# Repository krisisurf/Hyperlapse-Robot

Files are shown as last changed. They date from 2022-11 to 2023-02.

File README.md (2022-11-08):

# Hyperlapse-Robot
An remote-controlled electric mobile robot for creating hyperlapse videos using RaspberryPi and Arduino. Facilitates the process of capturing a so-called "hyperlapse/time-lapse" videos by precisely moving the position of the robot between the individual shots to add a depth-of-field effect to the final video.

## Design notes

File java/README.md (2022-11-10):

# Java Spring Application for Raspberry Pi

The Graphical User Interface of the project, which manages services to control the Arduino by sending JSON string with rules/commands to it.
The connection is one-directional (`RaspberryPI -> Arduino`) and it is made via `I2C protocol`.

## Setup Instructions
1. Open `java/Hyperlapse-Robot` project with IntelliJ or other Java IDE.
2. Run Maven command:
          ```
          mvn clean install
          ```
3. After the build is ready, copy the exported jar file `./target/Hyperlapse-Robot-0.0.1-SNAPSHOT.jar` to the Raspberry Pi
4. Enable I2C on the Raspberry Pi. You can see how [here](https://ozzmaker.com/i2c/).
5. Wire `RaspberryPi Zero 2W` with the `Arduino MEGA 2560` using pinouts.<table>
          <tr>
            <th>Raspberry Pi</th>
            <th>Arduino</th>
          </tr>
          <tr>
            <td>Ground</td>
            <td>Ground</td>
          </tr>
          <tr>
            <td>GPIO 2 Serial Data (I2C)</td>
            <td>SDA (D20)</td>
          </tr>
          <tr>
            <td>GPIO 3 Serial Clock (I2C)</td>
            <td>SCL (D21)</td>
          </tr>
    </table><p><span class="small">Optional for Arduino MEGA 2560: Digital IO Pins 20 and 21 can be configured as SDA (20) and SCL (21) to support I2C or I2C or Two Wire Interface (TWI) communication.</span></p>
6. Power on the Arduino and Raspberry Pi.
7. Run the java application on the Raspberry Pi. Navigate to the location of the jar file and run the command:
          ```
          sudo java -jar Hyperlapse-Robot-0.0.1-SNAPSHOT.jar
          ```
8. You are ready to open the GUI interface in the browser.

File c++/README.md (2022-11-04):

Using Arduino MEGA 2560 board.
Modules:
  * (4x) Step Motor 28BYj-48
  * (4x) ULN2003 driver board
  * Power source

arduino_steppers

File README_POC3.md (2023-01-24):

# Робот за създаване на hyperlapse/timelapse видеоклипове

## Описание:
> Електрически мобилен робот с отдалечено управление за създаване на "hyperlapse" видеоклипове с помощта на RaspberryPi компютър. Улеснява процеса на заснемането на така наречената "hyperlapse/time-lapse" фотография, като между отделните снимки се извършва прецизно преместване на позицията на робота, за да се придаде дълбочинен ефект на крайния видеоклип.
<sub>[Виж какво е hyperlapse тук.](https://youtu.be/y_4p6_KsqoE)</sub>

<table>
      <tr>
        <th>Софтуерна архитектура</th>
      </tr>
      <tr>
        <td>
          Software Architecture
        </td>
      </tr>
      </table>

>#### Frontend:</br>
>   - Мобилно приложение, което позволява на потребителя да създава и изпраща инструкции за движение към робота по интернет връзка.
>#### Hyperlapse Robot:</br>
>   - Spring Boot back-end - Сървърна програма, приемаща инструкции и изпращата ги към Control Board
>   - Control Board - Arduino микрокомпютър, който приема инструкции и контролира въртенето на стъпковите мотори
>   - Step Motors - стъпкови мотори, чрез които се извършва движението на робота и насочването на поставката за камера

## Главни функционалности на робота
1. Движение (напред, назад, с завой) по зададео разстояние и време за изпълнение.
2. Насочване на поставката за камера по зададени градусни мярки и време за изпълнение.
3. Мобилно приложение за управление, предназначено да се свързва с робота по WI-FI връзка.
   - бързо и лесно създаване на инструкции за движение
   - възможност за създаване на множество инструкции, които да се изпратят и изпълнят от робота
   - удобни за потребителя менюта за въвеждане на числови данни (растояние, време, градусни мярки).
4. Автоматично включване на робота, когато той се захранва от батерия/power bank

## Диаграми и изображения:
1. Хардуерна диаграма на архитектурата
    <table>
      <tr>
        <th>Hardware Wire диаграма</th>
      </tr>
      <tr>
        <td>
          Hardware Wire Architecture
        </td>
      </tr>
    </table>

2. DEMO, изработка по време на POC 2:
    <table>
          <th>
            <td>
                photo of the robot
            </td>
            <td>
                components inside the robot
            </td>
          </th>
    </table>

3. Изглед на мобилното приложение
      <table>
          <tr>
            <td>
                main window
            </td>
            <td>
                connection window
            </td>
            <td>
                create rule window
            </td>
          </tr>
          <tr>
            <td>
                create rule window
            </td>
            <td>
                create rule window
            </td>
            <td>
                main window
            </td>
          </tr>
      </table>

4. Изработка на 3D-модел на робота (3D принтер):
   - Вариант 1
   Hyperlapse-Robot
   - Подобрена версия на вариант 1
   Hyperlapse-robot-render-v2-jpeg

## Използвани технологии
- IntelliJ IDEA Community Edition
  - Разработка, чрез [Java Spring Boot](https://spring.io/projects/spring-boot).
  - библиотека [pi4j](https://mvnrepository.com/artifact/com.pi4j/pi4j-core), позволява изпращане/получаване на данни по I2C протокол.
- Arduino IDE
  - използвани библиотеки:
    - [Wire](https://www.arduino.cc/reference/en/language/functions/communication/wire/), позволява изпращане/получаване на данни по I2C протокол.
    - [AccelStepper](https://www.airspayce.com/mikem/arduino/AccelStepper/), позволява контролирането на стъпкови мотори.
    - [ArduinoJson](https://arduinojson.org/), позволява работа с JSON тип.
- Android Studio - софтуер за разработка на мобилни приложения. 
- Blender - софтуер за 3D моделиране.

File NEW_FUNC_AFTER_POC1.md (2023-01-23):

1. Create rule activity
    - user-friendly input menus. Faster and more user friendly inputs for numbers/values in the UI.
2. Configure Connection Activity
   - connection tester
   - connection validation
   - loading screen, while the connection is being tested
3. Check if the connection is established with the back-end every 5 seconds (in the MainActivity), that method is called Heartbeat
4. Send created rules to the back end via HTTP post
5. Autorun java backend application on raspberry boot with predefined values for 'wheel radius' and 'axle track'
6. Wheel radius and axle track values are received by the front end, when a connection is established wit hte backend

TODO:
1. Update architectural diagram
2. Описание на архитектурата спрямо диаграмата. От ляво на дясно или от Горе надоло (в зависимост от архитектурата) - flow
Едно изречение което отговаря на въпроса- What is?
Второ изрчечение което отговаря на въпроса - What does? 

DOCUMENTATION:
по-бързо селектиране на input
screenshot на issues
тегло на powerbankite
проблем с прекъсване на моторите
консумацията на всеки модул
избор на вид на моторите
спирачка/редуктурна част

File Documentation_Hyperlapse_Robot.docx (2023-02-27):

СОФИЙСКА ПРОФЕСИОНАЛНА ГИМНАЗИЯ ПО ЕЛЕКТРОНИКА „ДЖОН АТАНАСОВ“

Д И П Л О М Е Н П Р О Е К Т

Тема ““

Практическа част: „“

Дипломант: Кристиан Николаев Димитров 12в клас

Професия: TODO(481030) „ Приложен програмист“

Специалност: TODO(4810301) „Приложно програмиране“

Ръководител на дипломен проект: инж. Любица Димитрова

Дипломант:

/подпис/

Ръководител на Дипломен проект:

/подпис/

София

2022

Списък на използваните термини и съкращения

Timelapse - техника в фотографията, при която се правят множество снимки през определен интервал от време.

Hyperlapse - вид timelapse, при който камерата бива премествана в пространството след всеки заснет кадър.

IDE (интегрирана среда за разработка) - софтуерно приложение, което предоставя цялостна среда за разработване на софтуер на програмистите.

https://bg.wikipedia.org/wiki/Интегрирана_среда_за_разработка

C++ - програмен език от високо ниво, който се използва за разработване на различни видове приложения, включително операционни системи, игри и друг софтуер с висока производителност. Той е разработен от Бярне Страуструп в началото на 1980-те години като разширение на програмния език C. C++ е известен със своята ефективност, гъвкавост и възможностите за обектно-ориентирано програмиране (ООП), позволявайки на разработчиците да създават преизползваем код и да проектират сложни софтуерни системи.

Стъпков мотори - още наричан стъпков двигател е вид безколекторен постояннотоков двигател, който разделя пълното завъртане на няколко равни стъпки. Моторът може да се позиционира чрез сензор или друга обратна връзка (Closed Loop Control System). Той не може да бъде свързван директно към електрическа мрежа. Управлението на стъпковите електродвигатели се извършва само чрез компоненти на електрониката, като съществува голямо разнообразие на схеми и елементи за реализацията им, модули за вграждане и самостоятелни прибори.

https://bg.wikipedia.org/wiki/Стъпков_двигател

Входните/изходните пинове -

I²C - Тази комуникация е предназначена да позволи на множество "подчинени ИС" да комуникират с един или повече "главни ИС". Протоколът е предназначение за комуникация само на къси разстояния в рамките на едно устройство или между две свързани устройства. Изисква само два сигнални проводника за обмен на информация. I²C шината се състой от два сигнала: SCL и SDA. SCL е тактовият сигнал(часовника), а SDA е сигнала за данни. I²C има 7-битово адресно пространство с рядко използвано 10-битово разширение. Според това дали даден бит е за четене или писане (read/write) се определя какво действие ще прави главното устройство и съответно подчиненото, кое ще предава и кое ще получава данни.

https://www.electronicevolution.bg/bg-news-details-46.html

Master устройство -

STOP сигнал -

JSON -

Теоретична част

Увод

Живеем във време, в което дигиталните и механични устройства за автоматизация са неизменна част от живота ни. Подобни технологии спестяват време и усилия от страна на хората, както и намаляват разходи. Друго предимство на технологиите за автоматизация, към което разработчиците се стремят, е удобният за потребителя интерфейс. С нарастването на смартфоните и другите устройства технологията стана по-достъпна и по-лесна за използване от хора от всички възрасти и произход.

Фотографията и видеографията играят важна роля в социалните мрежи, телевизионната и рекламна индустрия, защото визуалното представяне е първото нещо, от което зависи дали вниманието на зрителите ще се задържи.

Като за начало, нека кажем какво е timelapse фотографията. Това е метод, при който фотограф прави поредица от снимки на предварително определен интервал за определена продължителност и след това представя тези снимки със скорост, по-бърза от реално време, под формата на видеоклип. За първи път тази техника е използвана от френския режисьор Жорж Мелиес през 1897 г.

Hyperlapse фотографията, която целим да улесним, е по-модерната и грабваща окото техника. Hyperlapse, всъщност е подвижен timelapse. Тоест между отделните снимки се извършва леко движение на камерата, като по този начин се придава дълбочинен ефект и по-голяма динамика на крайното видео. Проблемът при тази техника е, че за да се създаде подобен видеоклип е необходимо голямо усилие от страна на фотографа. Причината за това е, че неговата работа се състои в това да премества статива с камера, след всеки заснет кадър, което понякога може да продължава с часове.

TODO Къде би могъл да се приложи?

Цел на проекта:

Да се улесни процеса за заснемане на Hyperlapse видеоклипове, чрез автоматизирано решение. Да се създаде робот, който да може да се движи и да контролира посоката камера, предназначена за заснемане, като задаването на тези инструкции става през мобилно приложение, чрез отдалечен достъп към робота.

Изложение

Глава I. Анализ

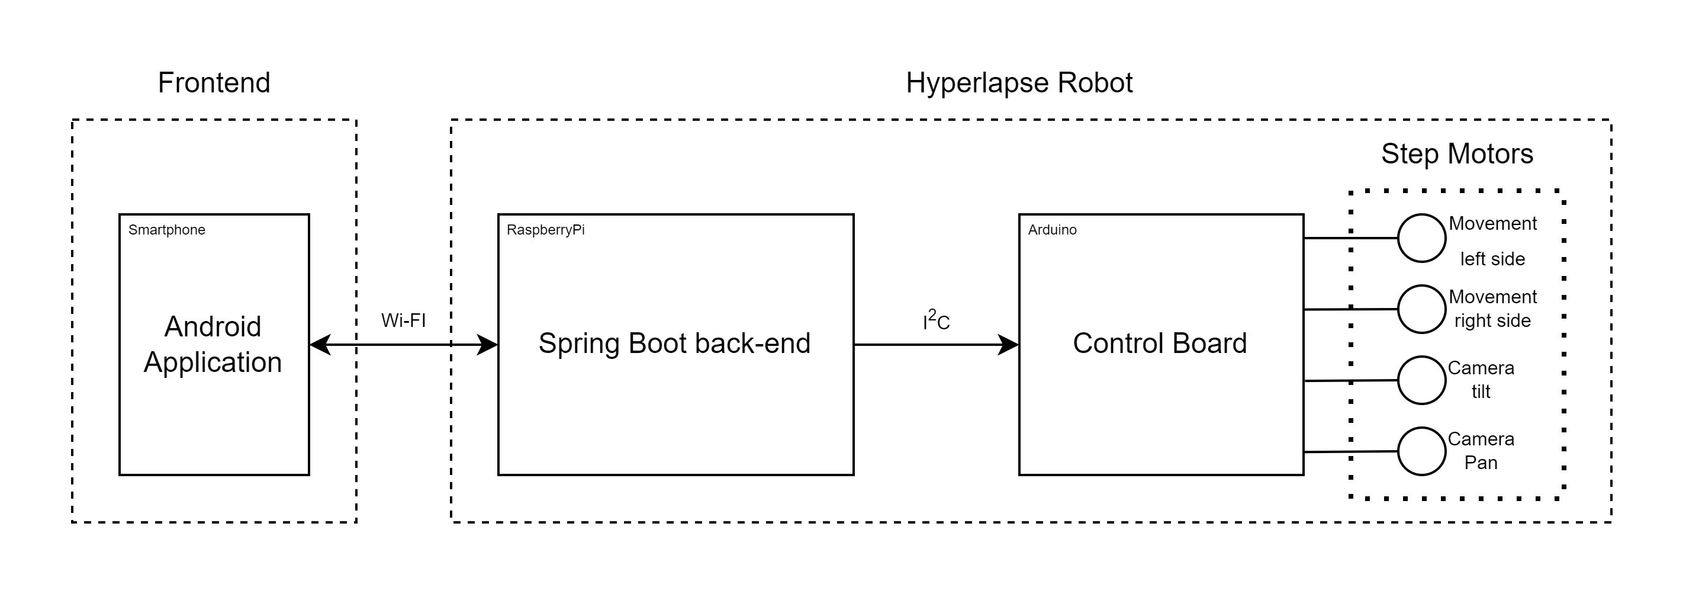
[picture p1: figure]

Фиг. 1. Софтуерна архитектура на проекта

С напредването на технологиите, микрокомпютрите и логически контролери стават все по-достъпни, поради масовото им производство. Едно от предимствата на тези устройства е, че те предразполагат лесното изграждането на прототипи или дори завършени системи. В роботиката, те са главните структурни единици, които управляват съответната машина.

Темата, която засягаме е електрически робот, който автоматизира процеса на заснемане на hyperlapse. За целта, той ще трябва да може да извършва движение в пространството, както и да контролира посоката на където да снима камерата. За да бъде навигиран от потребител, роботът има функция за управление от отдалечено разстояние.

За да може да се изработи такъв робот е необходима подготовка и изследване при изборът на компоненти. Важно е предварително да се предвижда дали те ще са съвместими един с друг, както и да няма твърде голяма консумация на електроенергия, за да се постигне по-голяма ефективност.

Проектът се разделя на няколко основни комуникиращи помежду си компонента, за да може да предава съществената информация, която засяга всеки един от тях. Нека разгледаме всеки един от тях, за да добием представа за архитектурата.

1.1 Първи компонент - Arduino

1.1.1 Какво е Arduino? - представлява хардуерна платка, която се състои от микроконтролер, явяващ се и микро компютър. Технологията е изградена с идеята да може да се използва лесно за софтуерни и хардуерни проекти. Компанията ,,Arduino LLC” се е погрижила за създаването на IDE, което позволява потребителите да разработват, компилират и качват код на Arduino платка. Програмният език, с който работят платките е опростена версия на C++. Тези устройства имат различни входове и изходи, които могат да се използват за свързване към сензори, електродвигатели, светлини и други електронни компоненти.

1.1.2 Каква е функцията на Arduino? - в нашия проект, Arduino ще се занимава с изпълнението на логиката, стояща зад контролирането на задвижващите и управляващите камерата стъпкови мотори. То също има функцията да приема инструкции за изпълнение, които получава от по-горните слоеве на архитектурата.

1.1.3 Кой модел Arduino използваме? - поради голямото разнообразие от различни видове модели Arduino платки, трябва да се вземе под внимание кой от тях би бил годен за работа в нашия робот. При избора на Arduino има няколко фактора, които трябва да се вземат под внимание:

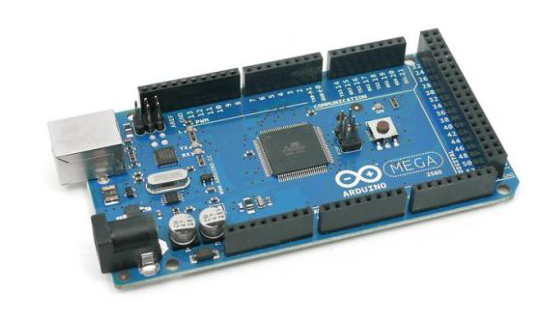
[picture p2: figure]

- Брой и тип на входните/изходните пинове - Трябва да се уверим, че платката разполага с достатъчно входни/изходни пинове, за да можем да свържем всички необходими компоненти за робота.
- Процесорна мощност - Ако роботът изисква бърза обработка на данни или изчисления, ще имаме нужда от по-мощна платка с по-бърз процесор.
- Размер и форма на платката - трябва да направим сметка, дали размерът на платката е съвместима с конструкцията на робота.

Относно целите на нашият проект, Arduino Mega 2560 е за предпочитание, защото има повече пинове и по-голяма процесорна мощност.

1.1.4 Как Arduino изпълнява своите задачи? - когато платката бива захранвана с електричество, тя автоматично започва изпълнението на предварително каченият програмен код, който сме разработили. Като за начало се инициализират изходните пинове, чрез които ще се управляват стъпковите мотори. Създава се и I²C връзка, която позволява на Arduino да комуникира с други електронни компоненти (в нашият случай RaspberryPI). След това то започва да чака информация от master устройството, като данните идват на порции от по 8 байта. Това ще се случва докато не се получи STOP сигнал (в случая символа‘$’, който в двоичен код е ‘00100100’). Порциите от байтове се събират в един стринг, чийто формат се очаква да бъде JSON, но това не зависи от master устройството (понеже то изпраща данните). Този JSON стринг представлява поредица от инструкции, които се отнасят до управлението на моторите. За да се намали обема на информация, която се предава в този JSON стринг сме направили съкращения в имената на отделните полета с цел за по-бързо получаване на данните по I²C връзката.

Нека разгледаме един пример за това какво съдържа един JSON стринг с инструкция:

Съкратен вариант, който Arduino използва. | Не съкратен вариант за по-добро възприемане на произхода на съкращенията.
{"rc":1,"wr":1.166666,"r":[{"lm":{"ds":100.0,"t":60.0},"rm":{"ds":100.0,"t":60.0},"pm":{"dg":50.0,"t":60.0},"tm":{"dg":-20.0,"t":60.0}}]} | { "rulesCount":1, "wheelRadius":1.166666, "rules":[ { "leftMotor":{ "distance":100.0, "executionTime":60.0 }, "rightMotor":{ "distance":100.0, "executionTime":60.0 }, "panMotor":{ "degree":50.0, "executionTime":60.0 }, "tiltMotor":{ "degree":-20.0, "executionTime":60.0 } } ] }

Този JSON обект има следните полета:

- “rc” / "rulesCount": Число, което указва броя на инструкциите, които се съдържат в списъка “r” / “rules”. В примера е демонстриран списък със само една инструкция.
- “wr” / "wheelRadius": Число, което представлява радиуса на задвижващите колела на робота в сантиметри. В случая радиусът на колелата е зададен на 1.166666 см.
- “r” / "rules": Списък от обекти, описващ поредица от инструкции. В този случай има само една инструкция в списъка. Всеки обект “r” / “rules” има следните свойства:
  - "leftMotor": Обект, който съдържа информация за стъпковият мотор, задвижващ лявото колело на робота. Това включва разстоянието (“ds” / “distance”), което моторът трябва да измине в сантиметри (в случая 100.0 см) и времето за изпълнение (“t” / “executionTime”) на това разстояние в секунди (в случая 60.0 сек).
  - "rightMotor": Обект, който съдържа информация за стъпковият мотор, задвижващ дясното колело на робота. Това включва разстоянието (“ds” / “distance”), което моторът трябва да измине в сантиметри (в случая 100.0 см) и времето за изпълнение (“t” / “executionTime”) на това разстояние в секунди (в случая 60.0 сек).
  - "panMotor": Обект, който съдържа информация за стъпковият мотор, контролиращ хоризонталната посока на камерата на робота. Това включва градусната мярка (“dg” / “degree”), до която моторът трябва да се завърти (в случая 50.0 градуса спрямо сегашната позиция) и времето за изпълнение (“t” / “executionTime”) на това завъртане в секунди (в случая 60.0 сек).
  - "tiltMotor": Обект, който съдържа информация за стъпковият мотор, контролиращ вертикалната посока на камерата на робота. Това включва градусната мярка (“dg” / “degree”), до която моторът трябва да се завърти (в случая 20.0 градуса спрямо сегашната позиция) и времето за изпълнение (“t” / “executionTime”) на това завъртане в секунди (в случая 60.0 сек).

Функционалност за завиване

1. Как ще се извършва завиването на робота?

Робота се движи посредством 2 стъпкови мотора, прикрепени от двете му страни. Чрез едновременно завъртане на моторите с различни скорости, би могло да се постигне ефект на завиване. За да се изчисли скоростта, трябва да се вземат в предвид разстоянието (което конкретният мотор трябва да измине) и времето за изпълнение.

2. Изчисляване на данните за извършване на завой.
- Като за начало е важно да се определят какви ще бъдат входните данни, които ще бъдат използвани за изчислението, както и изходните данни, които ще се изпращат, като инструкция към робота.

Входни данни (задаващи се от потребителя през мобилното управляващо приложение):

radius (cm)- радиус на завоя.

angle - ъгъл на завиване.

execution time (sec) - време на изпълнение.

axle track (cm) - дължината на оста между двете задвижващи колела. (Този параметър е зададен предварително, тъй като той е част от конструкцията на робота).

Изходни данни:

left motor distance (cm) - разстоянието, което левият мотор трябва да измине.

left motor execution time (sec) - времето на изпълнение на левият мотор.

right motor distance (cm) - разстоянието, което десният мотор трябва да измине.

right motor execution time (sec) - времето на изпълнение на десният мотор.

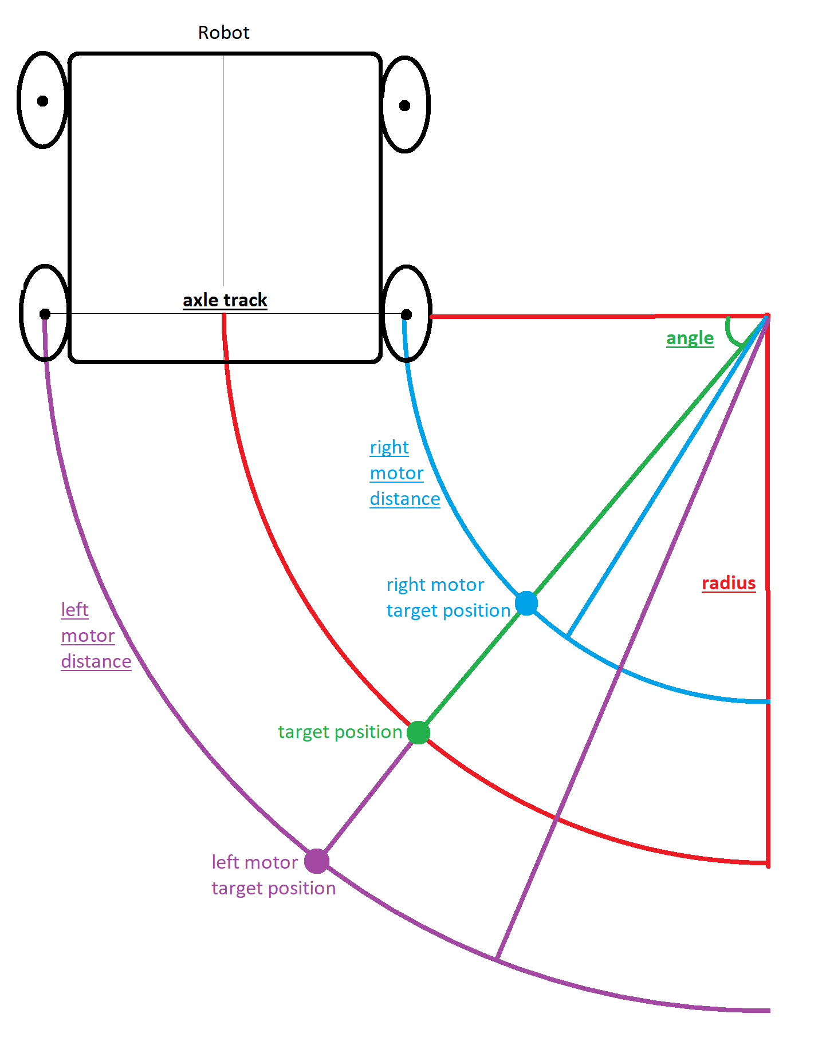
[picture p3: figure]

На диаграмата е демонстрирано как входните и изходните данни могат да се представят в графичен вид. radius (cm) - червената окръжност описва пътят по когото роботът ще се движи. Центърът на тази окръжност се намира на radius cm спрямо центъра на задвижващата ос (axle track / 2). angle - ъгълът на завой с връх стоящ в центъра на окръжността описваща пътя на движение, като едното рамо на ъгъла съвпада с продължението на оста за движение.

Left motor distance (cm) - разстоянието, което левият мотор трябва да измине се изразява, чрез дъгата започваща от лявото колело и завършваща при точката left motor target position от лилавата окръжност.

Формула:

leftMotorPathRadius =radius−(angle)/(|angle|)⋅(axleTrack)/2

leftMotorDistance =(π ⋅angle)/180⋅leftMotorPathRadius

right motor distance (cm) - разстоянието, което десният мотор трябва да измине се изразява, чрез дъгата започваща от дясното колело и завършваща при точката right motor target position от синята окръжност.

Формула:

rightMotorPathRadius =radius+(angle)/(|angle|)⋅(axleTrack)/2

rightMotorDistance =(π ⋅angle)/180⋅rightMotorPathRadius

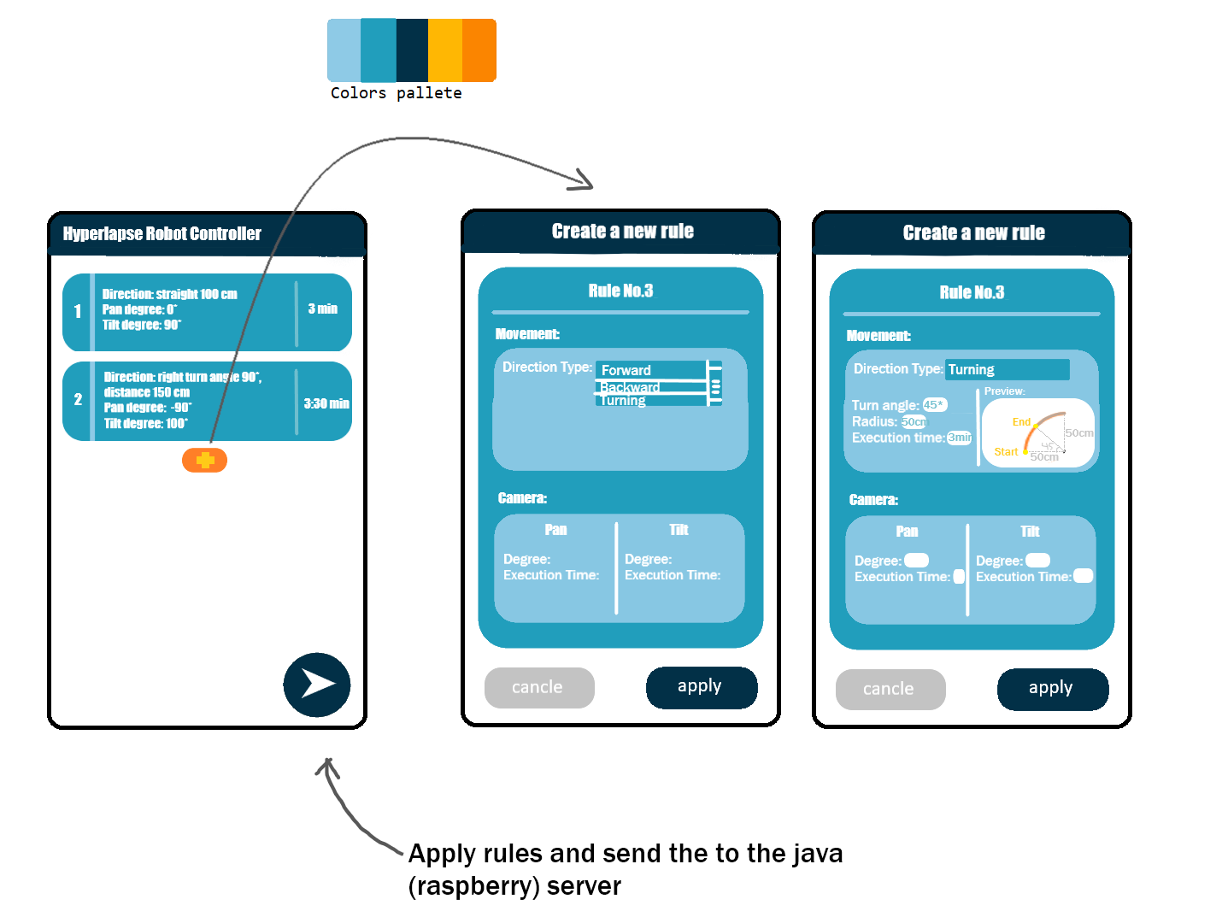
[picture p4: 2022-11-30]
frontend/app_frontend_paint.png

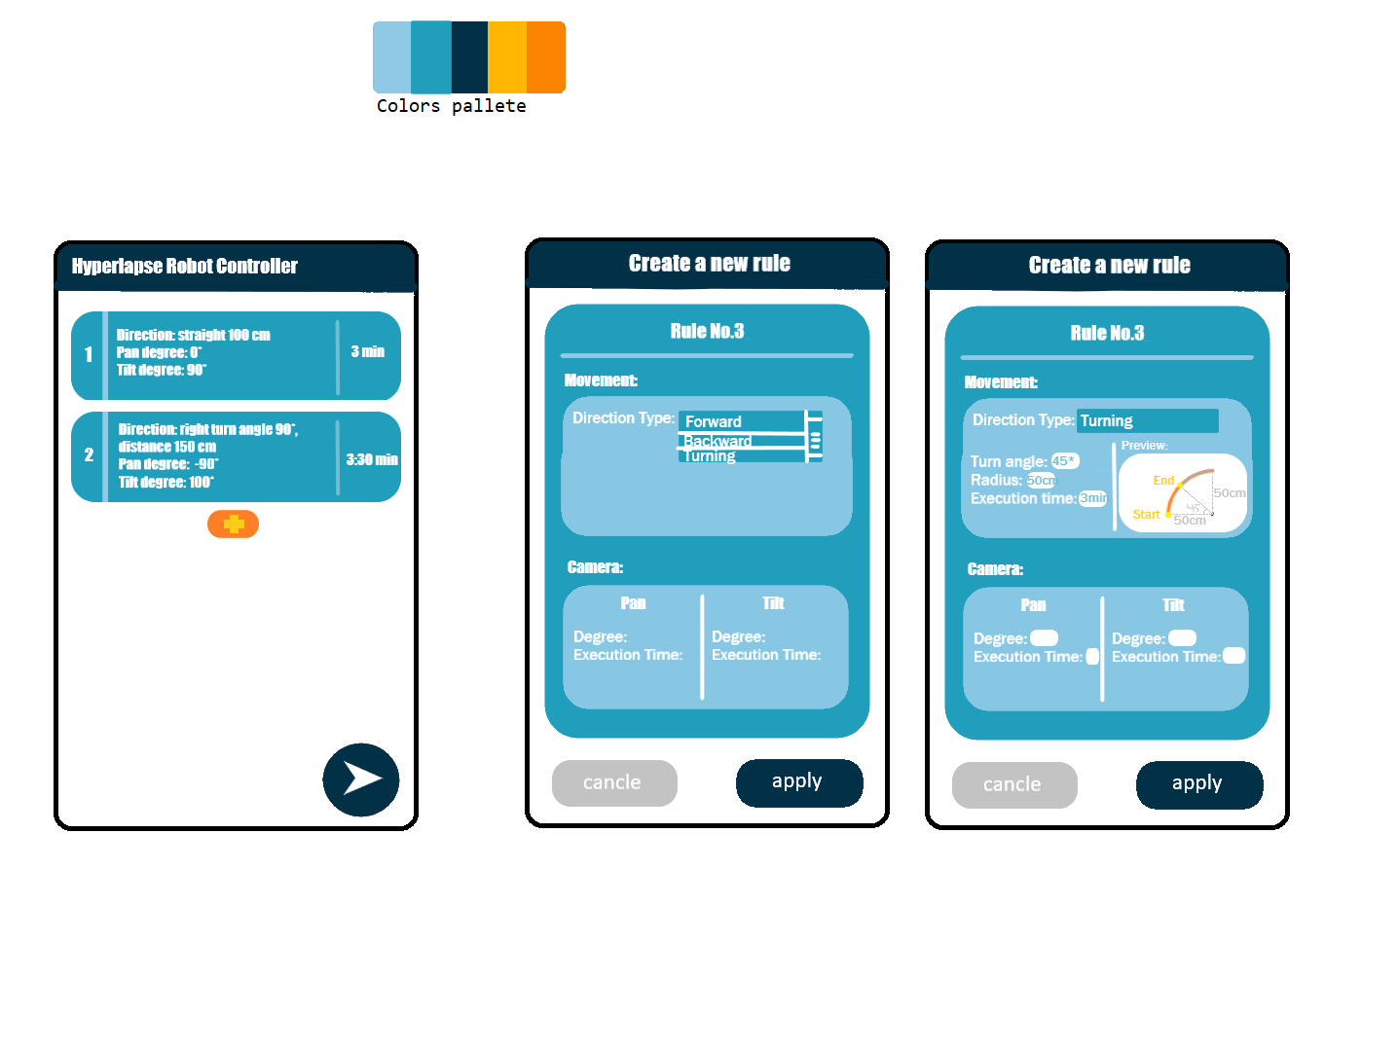
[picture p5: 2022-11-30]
frontend/app_frontend_paint.bmp.png

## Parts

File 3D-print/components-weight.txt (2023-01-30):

middleWall = 12g x2
sideWall = 35g x2
motorHolder = 5g x2
gearHolder = 5g x2
lightWheel = 21g (100% infill density) x6
smallGear = 1g (100% infill density) x2
bigGear = 4g (100% infill density) x2

total: 250g

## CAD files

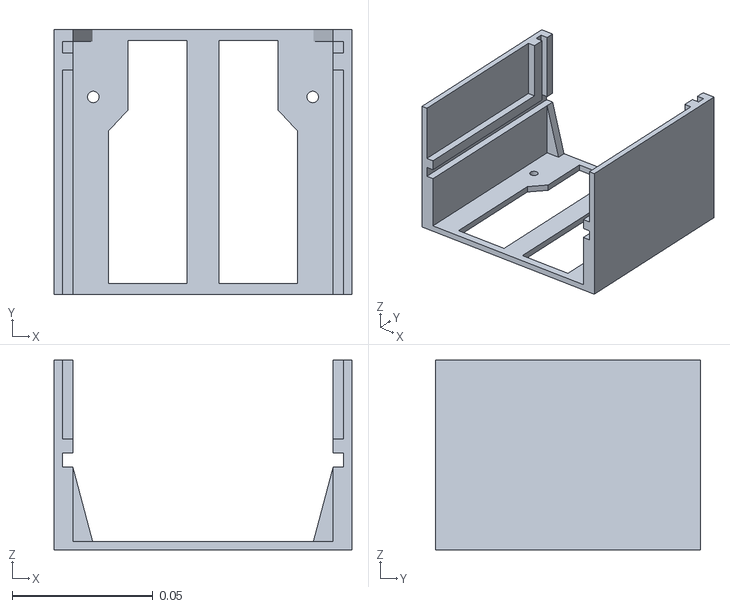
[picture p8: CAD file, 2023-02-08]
3D-print/components-stl/up-controlBoxBody1.stl
0.106 x 0.0942 x 0.0674

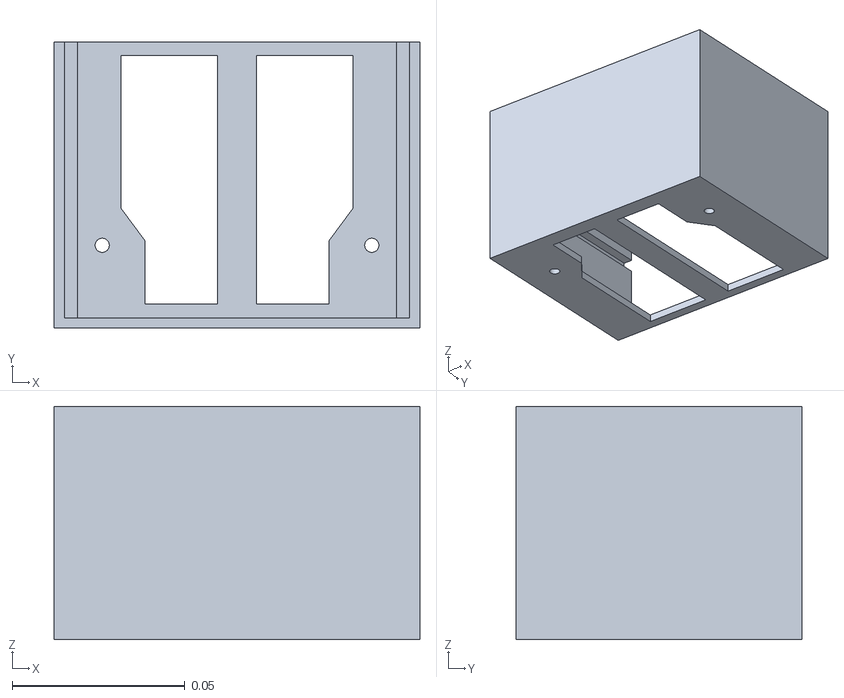
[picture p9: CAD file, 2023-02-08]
3D-print/components-stl/up-controlBoxBody2.stl
0.106 x 0.0828 x 0.0674

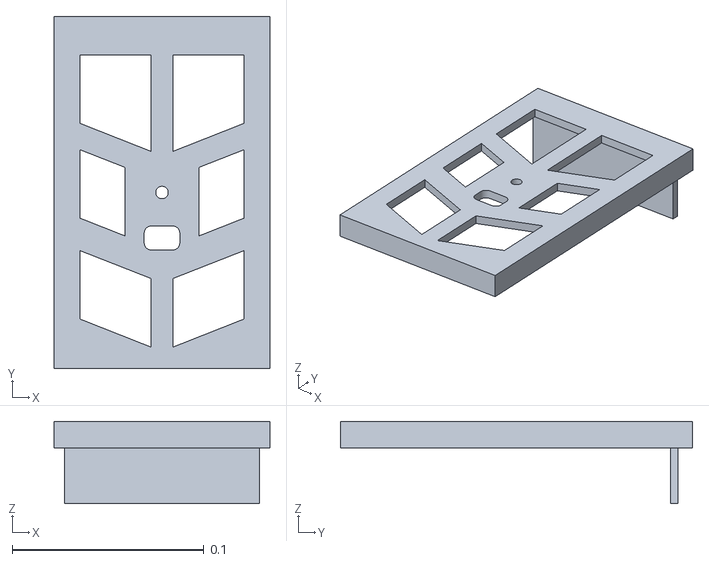
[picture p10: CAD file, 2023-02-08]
3D-print/components-stl/up-boxControllerTop.stl
0.112 x 0.184 x 0.0429

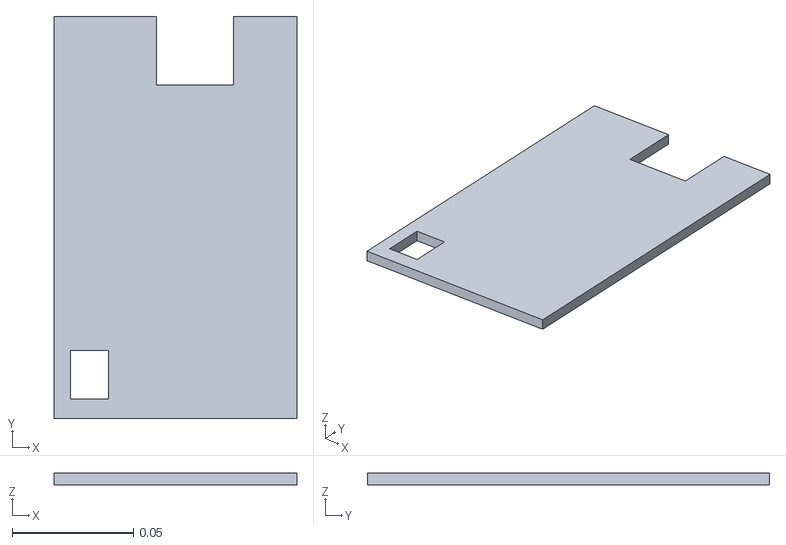
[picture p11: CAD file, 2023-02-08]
3D-print/components-stl/up-circuitPlate.stl
0.0999 x 0.165 x 0.0049

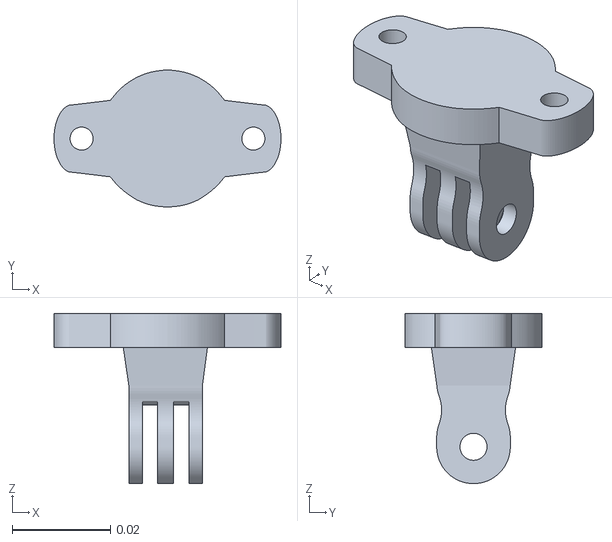
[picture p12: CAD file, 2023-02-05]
3D-print/components-stl/up-panMotorHolder.stl
0.0462 x 0.0279 x 0.0347

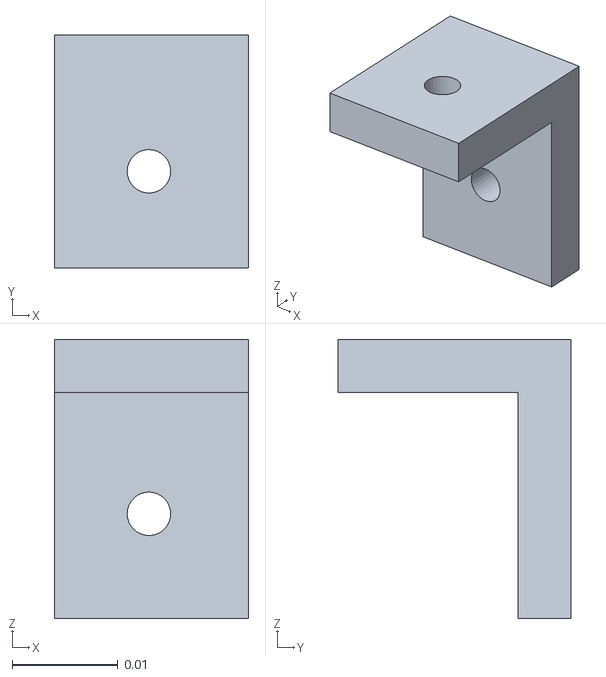
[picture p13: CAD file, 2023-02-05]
3D-print/components-stl/up-box90degHolder.stl
0.0184 x 0.022 x 0.0264

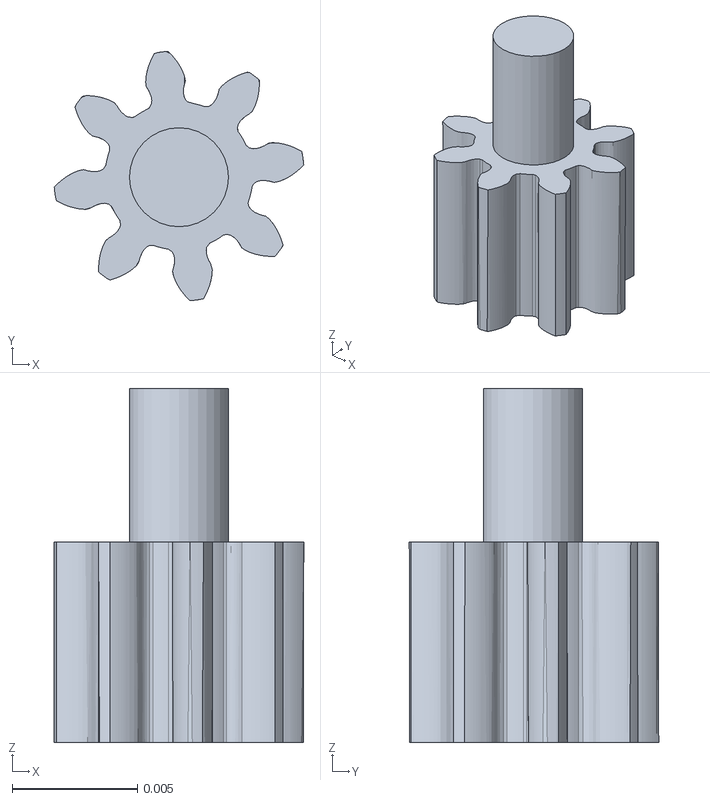
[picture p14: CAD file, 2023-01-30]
3D-print/components-stl/smallGear.stl
0.00996 x 0.00996 x 0.0141

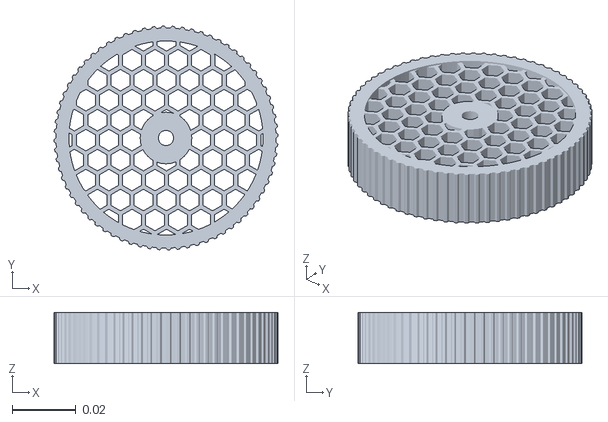
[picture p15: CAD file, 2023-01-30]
3D-print/components-stl/heavierWheel.stl
0.07 x 0.07 x 0.016

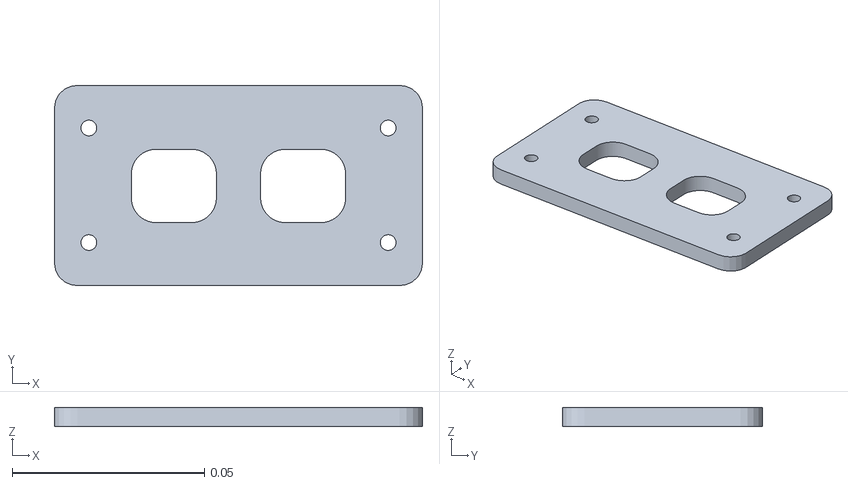
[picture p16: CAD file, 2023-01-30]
3D-print/components-stl/middleWall.stl
0.0958 x 0.0521 x 0.005

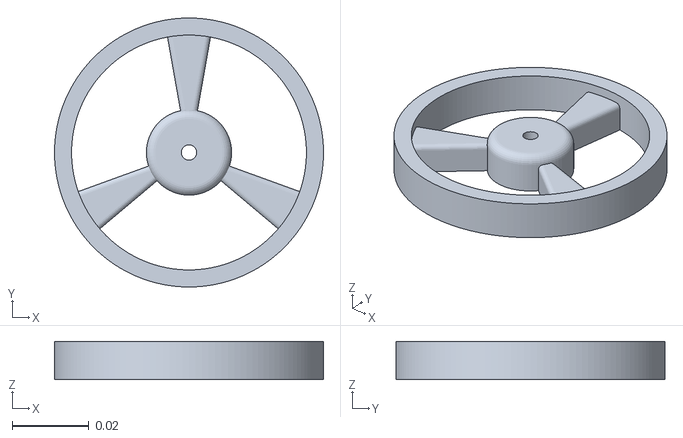
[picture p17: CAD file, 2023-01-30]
3D-print/components-stl/lightWheel.stl
0.07 x 0.07 x 0.01

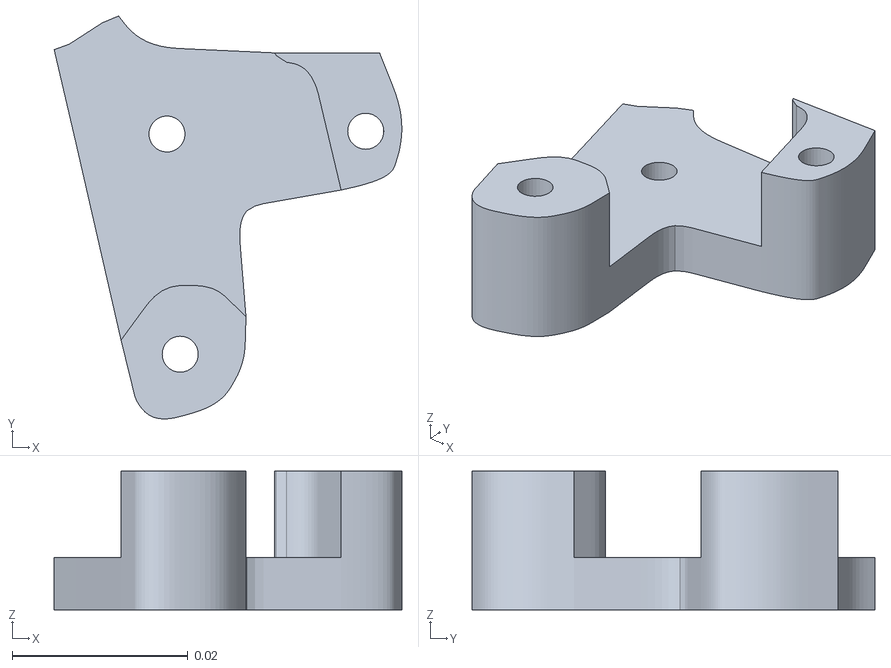
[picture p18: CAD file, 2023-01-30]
3D-print/components-stl/gearHolder.stl
0.0396 x 0.0459 x 0.0158

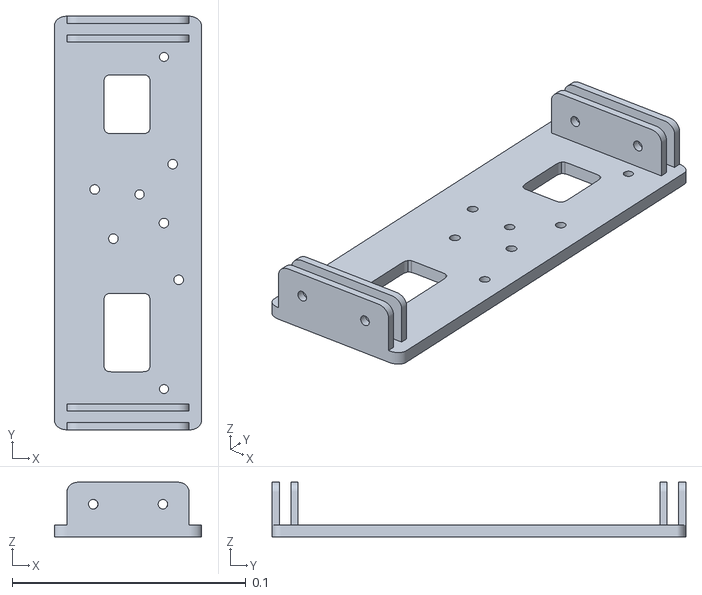
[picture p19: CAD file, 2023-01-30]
3D-print/components-stl/sideWall.stl
0.0629 x 0.177 x 0.0234

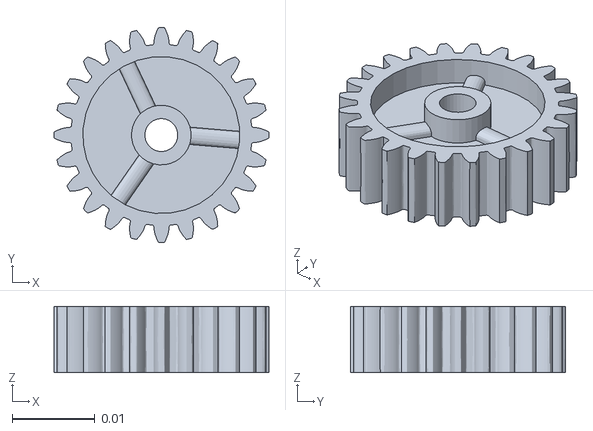
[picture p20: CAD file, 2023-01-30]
3D-print/components-stl/bigGear.stl
0.026 x 0.026 x 0.008

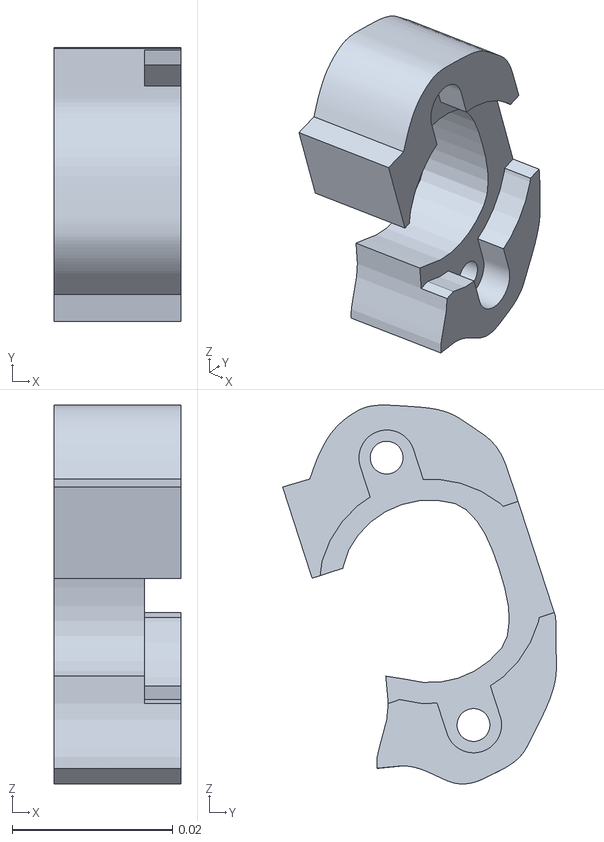
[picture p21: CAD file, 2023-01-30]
3D-print/components-stl/motorHolder.stl
0.0158 x 0.0342 x 0.0473

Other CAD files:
3D-print/assembly.blend

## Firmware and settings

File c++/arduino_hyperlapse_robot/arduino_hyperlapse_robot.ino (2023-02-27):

// Include the AccelStepper library:
#include <AccelStepper.h> // library by Patrick Wasp
#include <MultiStepper.h> // library by Patrick Wasp
#include <ArduinoJson.h> // library by Benoit Blanchon
#include <Wire.h>

#define BUZZER_PIN 9 // buzzer to arduino pin 9
const int BUZZER_TIME_MILLIS = 100; // How long will the buzzer make sound after every rule load

// Define the AccelStepper interface type; 4 wire motor in half step mode:
#define MotorInterfaceType 8

// Initialize with pin sequence IN1-IN3-IN2-IN4 for using the AccelStepper library with 28BYJ-48 stepper motor:
AccelStepper stepperLeft = AccelStepper(MotorInterfaceType, 50, 46, 48, 44);  // IMPORTANT!!! THE PINS FOR THE LEFT SIDE MOTOR ARE FLIPPED. This will lead the left side motor to rotate in the opposite direction to the right side motor
AccelStepper stepperRight = AccelStepper(MotorInterfaceType, 45, 49, 47, 51);
AccelStepper stepperPan = AccelStepper(MotorInterfaceType, 29, 25, 27, 23); // Flipped to be more user-intuitive
AccelStepper stepperTilt = AccelStepper(MotorInterfaceType, 22, 26, 24, 28);



// Define a StepMotor structure to help organizing the motors
struct StepMotor{
  String name;                      // name of the stepper motor as defined in the JSON rule document
  AccelStepper &stepper;            // Instance of the stepper
};

// Initialize a stepper motors array
StepMotor steppers[4] = {
    {"lm", stepperLeft},
    {"rm", stepperRight},
    {"pm", stepperPan},
    {"tm", stepperTilt}
  };

// The number of steps for a 360 degrees rotation in the AccelStepper library.
// NOTE: Values for step motor with different number of steps per revolution should be mapped/scaled to this
const int LIB_STEPS_PER_REVOLUTION = 4096;

String receivedStringFromMaster = "";
bool isFullyReceivedFromMaster = false;
bool readRequest = false;

void setup() {
  pinMode(BUZZER_PIN, OUTPUT);
  
  // Set the maximum steps per second:
  stepperLeft.setMaxSpeed(1024);
  stepperLeft.setMinPulseWidth(80000);

  stepperRight.setMaxSpeed(1024);
  stepperRight.setMinPulseWidth(80000);

  stepperPan.setMaxSpeed(1024);
  stepperPan.setMinPulseWidth(80000);

  stepperTilt.setMaxSpeed(1024);
  stepperTilt.setMinPulseWidth(80000);
  
  // setStepMotorsOutputs(false);  // Disable motors pinouts by default to save power.
  
  Wire.begin(8);                // join I2C bus with address #8
  Wire.onReceive(receiveEvent); // register event

  // Unmark this to get program logs. NOTE THAT THIS SLOWS THE PROGRAM and also the BUZZER will not work properly
  // Serial.begin(9600);
}

void loop() {
  static DynamicJsonDocument rules(2000);    // Json object that will contain the movement rules
  static int currentRuleIndex;
  static int rulesCount;
  static double wheelRadius = 5.0; // Default value of the wheel radius is 5 cm. It will be changed when a rule from the backend is received.
  static bool rulesFinished;

  static int lastTimeLoopedBuzzer = millis(); // last time looped millisecond
  static int buzzerTimeLeft; // How much time left to stop the buzzer from producing noise

  int currentTime = millis();
  // UPDATE BUZZER
  if(buzzerTimeLeft > 0){
    int timePassed = currentTime - lastTimeLoopedBuzzer;
    buzzerTimeLeft -= timePassed;
    tone(BUZZER_PIN, 300);
  } else {
    noTone(BUZZER_PIN);
  }
  lastTimeLoopedBuzzer = currentTime;
  // End of UPDATE BUZZER

  if(readRequest){
    readAndAnswerRequestFromMaster();
    readRequest = false;
  }
  
  // Waits for JSON format with movement rules to be inputted to the Serial
  if(isFullyReceivedFromMaster){
    Serial.println("New rules received");
    rules.clear();
    deserializeJSON(rules, receivedStringFromMaster);
    receivedStringFromMaster = "";
    isFullyReceivedFromMaster = false;
    
    resetMotors();
    rulesCount = rules["rc"];
    wheelRadius = rules["wr"];
    currentRuleIndex = 0;
    rulesFinished = false;
    
    // setStepMotorsOutputs(true);
  }

  // Does not move the motors, if there are no movement rules or they have been already finished
  if(rulesCount == 0 || rulesFinished)
    return;

  // Run motors  
  bool hasFinished = runMotorsToPosition();

  // Stops there if the motors have not reached their target positions
  if(!hasFinished)
    return;
  
  if(currentRuleIndex < rulesCount){
    buzzerTimeLeft = BUZZER_TIME_MILLIS; // Makes a buzzer noise
    
    // Loads the next rule from the Json Document
    loadRule(rules, currentRuleIndex, wheelRadius);
    currentRuleIndex++;
  }else{
    rulesFinished = true;
    // All rules have been finished, so we disable motor outputs to save power
    // setStepMotorsOutputs(false);
  }
}

/*
  Rotates every step motor, which has not yet reached its target position.
  Returns:
    * true   -> if all the motors have reached their target position and the total execution time of the rule has passed
    * false  -> if one or more step motors have not yet reached their target position or the total execution time of the rule has not passed
*/
bool runMotorsToPosition(){
  int steppersFinished = 0;
  static int lastTime = millis();
  
  for(StepMotor stepMotor : steppers){
    AccelStepper &as = stepMotor.stepper;
            
    as.setSpeed(as.speed());
    as.runSpeedToPosition();

    if(as.distanceToGo() == 0)
      steppersFinished++;
  }
  
  return steppersFinished == 4;
}


// deserializes json string
void deserializeJSON(DynamicJsonDocument& rules, String json){
  // Deserialize the JSON document
  DeserializationError error = deserializeJson(rules, json);

  // Test if parsing succeeds.
  if (error) {
    Serial.print(F("deserializeJson() failed: "));
    Serial.println(error.f_str());
    return;
  }
}


/*
  Loads a rule from json document and sets the motors target position and speed and etc.
  Parameters:
  * rules             -> json document with structure for the rules
  * ruleIndexToLoad   -> index of the rule from the rules document, which will be loaded
*/
void loadRule(DynamicJsonDocument& rules, const int ruleIndexToLoad, const double wheelRadius){
    Serial.print("Initializing rule No.");Serial.println(ruleIndexToLoad);
    
    // Sets left and right side step motors
    for(int i = 0; i < 2; i++){
      StepMotor stepMotor = steppers[i];
      double distance = rules["r"][ruleIndexToLoad][stepMotor.name]["ds"];
      double executionTime = rules["r"][ruleIndexToLoad][stepMotor.name]["t"];
      
      long steps = convertCentimetersToSteps(distance, wheelRadius, LIB_STEPS_PER_REVOLUTION);
      double speed = convertStepsAndExecutionTimeToSpeed(steps, executionTime);

      stepMotor.stepper.move(steps);
      stepMotor.stepper.setSpeed(speed);

      // Displays received and calculated data
      Serial.print("Motor: ");Serial.println(stepMotor.name);
      Serial.print("Distance: ");Serial.println(distance);
      Serial.print("Execution time: ");Serial.println(executionTime);
      Serial.print("Steps: ");Serial.println(steps);
      Serial.print("Speed: ");Serial.println(speed);
      Serial.print("Motor target position: ");Serial.println( stepMotor.stepper.targetPosition());
      Serial.println();
    }

    // Sets pan and tilt step motors
    for(int i = 0; i < 2; i++){
      StepMotor stepMotor = steppers[i + 2];
      double degrees = rules["r"][ruleIndexToLoad][stepMotor.name]["dg"];
      double executionTime = rules["r"][ruleIndexToLoad][stepMotor.name]["t"];
        
      long steps = convertDegreesToSteps(degrees, LIB_STEPS_PER_REVOLUTION);
      double speed = convertStepsAndExecutionTimeToSpeed(steps, executionTime);

      stepMotor.stepper.move(steps);
      stepMotor.stepper.setSpeed(speed);

      // Displays received and calculated data
      Serial.print("Motor: ");Serial.println(stepMotor.name);
      Serial.print("Degrees: ");Serial.println(degrees);
      Serial.print("Execution time: ");Serial.println(executionTime);
      Serial.print("Steps: ");Serial.println(steps);
      Serial.print("Speed: ");Serial.println(speed);
      Serial.print("Motor target position: ");Serial.println( stepMotor.stepper.targetPosition());
      Serial.println();
    }
}

/*
  Removes target positions of all the motors.
*/
void resetMotors(){
   for(int i = 0; i < 4; i++){
      StepMotor stepMotor = steppers[i];
      stepMotor.stepper.setCurrentPosition(0);
      stepMotor.stepper.moveTo(0);
   }
}

/* 
  Function that executes whenever data is received from master (in our case master is the Raspberry Pi).
  This function is registered as an event, see setup()
*/
void receiveEvent(int howMany) {
  static const char STOP_RULES_SIGNAL = '$'; // When arduino receive this character, it will load the received json document with rules
  static const char STOP_REQUEST_SIGNAL = '^'; // When arduino receive this character, it will load the received json document with rules
  isFullyReceivedFromMaster = false;
  
  while (Wire.available()) { // loop through all but the last
    char c = Wire.read(); // receive byte as a character
    if(c == STOP_RULES_SIGNAL){
      isFullyReceivedFromMaster = true;
      Serial.println("Received data from master:");
      Serial.println(receivedStringFromMaster);
      return;
    }else if(c == STOP_REQUEST_SIGNAL){
      readRequest = true;
      return;
    }
    
    receivedStringFromMaster.concat(c);
  }
}

void readAndAnswerRequestFromMaster(){
  static DynamicJsonDocument requests(200);
  
  requests.clear();
  deserializeJSON(requests, receivedStringFromMaster);

  Serial.print("Received request from master: ");
  Serial.println(receivedStringFromMaster);
  receivedStringFromMaster = "";

  String requestData = requests["rd"];
  Serial.print("RequestData: ");
  Serial.println(requestData);
  if(requestData.equals("ROBOT_HARDWARE_PROPERTIES")){
    Serial.println("Trying to send 'testing' message to master");
    Wire.write('b');
    Serial.println("Data should have been sent???");
  }
}

/*
  Enables or disables pinout outputs for every step motor in the array 'steppers'
  Parameters:
  * enabledOutputs  -> value of 'true' will enable outputs and value 'false' will disable outputs to save power
*/
void setStepMotorsOutputs(bool enabledOutputs){
  if(enabledOutputs)
    for(StepMotor stepMotor : steppers)
      stepMotor.stepper.enableOutputs();
  else
    for(StepMotor stepMotor : steppers)
      stepMotor.stepper.disableOutputs();
}

/*
    Converts distance to number of steps (step motor), that it takes for a wheel with radius to travel the given distance.
    Parameters:
    * centimeters               -> distance in centimeters
    * wheelRadiusInCentimeters  -> Radius of the rotational wheel placed on the stepper motor
    * stepsPerRevolution        -> The number of steps that the motor makes for one revolution (360 degrees)

    Returns:
    * The number of steps that it takes to travel the given distance
*/
long convertCentimetersToSteps(double centimeters, double wheelRadiusInCentimeters, const int stepsPerRevolution){
  double pi = 3.141592;  
  double wheelPerimeter = 2 * pi * wheelRadiusInCentimeters;
  
  double revolutionsToMake = centimeters / wheelPerimeter;
  
  long steps = stepsPerRevolution * revolutionsToMake;
  return steps;
}

/*
    Calculates the time in seconds that will take to rotate a step motor for a certain number of steps.
    Parameters:
    * steps -> number of steps
    * speed -> steps per second, rotational speed of the step motor.
    Returns:
    * time in seconds
*/
double convertStepsToSeconds(long steps, double speed){
  double timeToCompleteInSeconds = 1.0 * steps / speed;
  return timeToCompleteInSeconds;
}

/*
    Calculates the speed at which a motor must move to a certain number of steps in a for a given time.
    Parameters:
    * steps          -> number of steps
    * executionTime  -> the time for rotating the given number of steps
    Returns:
    * speed in steps per second
*/
double convertStepsAndExecutionTimeToSpeed(long steps, double executionTime){
  double speed = 1.0 * steps / executionTime;
  return speed;  
}

/*
    Converts degrees to number of steps (step motor), that it takes for a motor to move to the given number of degrees.
    Parameters:
    * degrees            -> degrees from current position
    * stepsPerRevolution -> The number of steps that the motor makes for one revolution (360 degrees)
    Returns:
    * The number of steps that it takes to move the given number of degrees
 */
long convertDegreesToSteps(double degrees, const int stepsPerRevolution) {
    return (long) (stepsPerRevolution * degrees / 360);
}

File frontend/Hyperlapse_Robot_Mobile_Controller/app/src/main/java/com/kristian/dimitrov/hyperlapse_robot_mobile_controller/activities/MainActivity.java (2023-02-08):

package com.kristian.dimitrov.hyperlapse_robot_mobile_controller.activities;

import android.app.Activity;
import android.content.Intent;
import android.os.Bundle;

import com.google.android.material.floatingactionbutton.FloatingActionButton;
import com.kristian.dimitrov.hyperlapse_robot_mobile_controller.R;
import com.kristian.dimitrov.hyperlapse_robot_mobile_controller.adapters.StagedRulesAdapter;
import com.kristian.dimitrov.hyperlapse_robot_mobile_controller.entity.ArduinoRobot;
import com.kristian.dimitrov.hyperlapse_robot_mobile_controller.entity.ArduinoRobotConnection;
import com.kristian.dimitrov.hyperlapse_robot_mobile_controller.entity.RuleEntity;
import com.kristian.dimitrov.hyperlapse_robot_mobile_controller.entity.RulesManagerEntity;
import com.kristian.dimitrov.hyperlapse_robot_mobile_controller.entity.stepper.CameraStepMotorEntity;
import com.kristian.dimitrov.hyperlapse_robot_mobile_controller.entity.stepper.MovementStepMotorEntity;

import androidx.appcompat.app.AppCompatActivity;
import androidx.appcompat.widget.Toolbar;
import androidx.recyclerview.widget.LinearLayoutManager;
import androidx.recyclerview.widget.RecyclerView;

import android.util.Log;
import android.view.View;
import android.widget.Button;
import android.widget.TextView;
import android.widget.Toast;

public class MainActivity extends AppCompatActivity {

    private static final String TAG = "MainActivity";
    private static final int REQUEST_CODE_CONFIGURE_CONNECTION = 100;
    private static final int REQUEST_CODE_CREATE_RULE = 101;

    private ArduinoRobot arduinoRobot;
    private ArduinoRobotConnection arduinoRobotConnection;

    private StagedRulesAdapter stagedRulesAdapter;

    @Override
    protected void onCreate(Bundle savedInstanceState) {
        super.onCreate(savedInstanceState);
        setContentView(R.layout.activity_main);

        TextView tvConnectionStatus = findViewById(R.id.tvConnStatus);
        Thread uiThread = new Thread(() -> {
            if (arduinoRobotConnection.isConnectionEstablished()) {
                tvConnectionStatus.setText(getString(R.string.connected_status));
                tvConnectionStatus.setTextColor(getColor(R.color.green));
            } else {
                tvConnectionStatus.setText(getString(R.string.not_connected_status));
                tvConnectionStatus.setTextColor(getColor(R.color.red));
            }
        });

        final double defaultWheelRadius = 5; // Default wheelRadius, which may be updated when connection with the robot is established
        final double defaultAxleTrack = 10; // Default axleTrack, which may be updated when connection with the robot is established
        final MovementStepMotorEntity leftMotor = new MovementStepMotorEntity(5, 64, 16);
        final MovementStepMotorEntity rightMotor = new MovementStepMotorEntity(5, 64, 16);
        final CameraStepMotorEntity cameraPanMotor = new CameraStepMotorEntity(64, 16);
        final CameraStepMotorEntity cameraTiltMotor = new CameraStepMotorEntity(64, 16);

        arduinoRobot = new ArduinoRobot();
        arduinoRobot.setHardwareData(defaultWheelRadius, defaultAxleTrack, leftMotor, rightMotor, cameraPanMotor, cameraTiltMotor);
        arduinoRobotConnection = new ArduinoRobotConnection(5000) {
            @Override
            public void onConnectionStatusListener(boolean isConnectionEstablished) {
                runOnUiThread(uiThread);
            }
        };
        arduinoRobotConnection.start();

        Toolbar toolbar = findViewById(R.id.toolbar);
        toolbar.setTitle("Hyperlapse Robot Controller");
        setSupportActionBar(toolbar);

        FloatingActionButton buttonSendRules = findViewById(R.id.btn_send_rules);
        buttonSendRules.setOnClickListener(this::sendStagedRules);

        FloatingActionButton buttonConfigureConnection = findViewById(R.id.btn_configure_connection);
        buttonConfigureConnection.setOnClickListener(this::openConfigureConnectionActivity);

        Button buttonAddRule = findViewById(R.id.btn_add_rule);
        buttonAddRule.setOnClickListener((v) -> openCreateRuleActivity(-1));

        stagedRulesAdapter = new StagedRulesAdapter(MainActivity.this, arduinoRobot.getRulesManagerEntity().getRules());
        stagedRulesAdapter.setOnEditClickListener((ruleEntity -> {
            int indexOfRuleEntity = arduinoRobot.getRulesManagerEntity().getRules().indexOf(ruleEntity);
            openCreateRuleActivity(indexOfRuleEntity);
        }));
        RecyclerView recyclerView = findViewById(R.id.rulesRecyclerView);
        recyclerView.setAdapter(stagedRulesAdapter);
        recyclerView.setLayoutManager(new LinearLayoutManager(MainActivity.this));
    }

    private void sendStagedRules(View view) {
        RulesManagerEntity rulesManagerEntity = arduinoRobot.getRulesManagerEntity();

        if (rulesManagerEntity.size() == 0) {
            Toast.makeText(MainActivity.this, "Error! Create rules first.", Toast.LENGTH_LONG).show();
            return;
        }

        boolean isSent = arduinoRobotConnection.tryToSendRules(arduinoRobot.getRulesManagerEntity());

        if (isSent) {
            Toast.makeText(MainActivity.this, "Rules has been sent successfully.", Toast.LENGTH_LONG).show();
            return;
        }

        if (!arduinoRobotConnection.isConnectionEstablished()) {
            Toast.makeText(MainActivity.this, "Error! Connect with the robot.", Toast.LENGTH_LONG).show();
        } else {
            Toast.makeText(MainActivity.this, "Internal application error. Couldn't send rules to the robot.", Toast.LENGTH_LONG).show();
        }
    }

    /**
     * Opens CreateRuleActivity with an option for template ruleEntity
     *
     * @param indexOfRuleEntity template RuleEntity for editing its properties. Set to -1 if you want to create a new rule
     */
    private void openCreateRuleActivity(int indexOfRuleEntity) {
        if (!arduinoRobotConnection.isConnectionEstablished()) {
            Toast.makeText(MainActivity.this, "Please, connect with the Robot, before adding a rule.", Toast.LENGTH_SHORT).show();
            //return;
        }

        Intent intent = new Intent(MainActivity.this, CreateRuleActivity.class);
        intent.putExtra(CreateRuleActivity.ARDUINO_ROBOT_CODE, arduinoRobot);
        intent.putExtra(CreateRuleActivity.RULE_ENTITY_INDEX_CODE, indexOfRuleEntity);
        startActivityForResult(intent, REQUEST_CODE_CREATE_RULE);
    }

    private void openConfigureConnectionActivity(View view) {
        Intent intent = new Intent(MainActivity.this, ConfigureConnectionActivity.class);
        startActivityForResult(intent, REQUEST_CODE_CONFIGURE_CONNECTION);
    }

    @Override
    protected void onActivityResult(int requestCode, int resultCode, Intent data) {
        super.onActivityResult(requestCode, resultCode, data);
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

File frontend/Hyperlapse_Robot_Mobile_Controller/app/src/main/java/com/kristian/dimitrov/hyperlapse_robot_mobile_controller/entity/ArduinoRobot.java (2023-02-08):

package com.kristian.dimitrov.hyperlapse_robot_mobile_controller.entity;

import com.kristian.dimitrov.hyperlapse_robot_mobile_controller.entity.stepper.CameraStepMotorEntity;
import com.kristian.dimitrov.hyperlapse_robot_mobile_controller.entity.stepper.MovementStepMotorEntity;

import java.io.Serializable;

public class ArduinoRobot implements Serializable {

    /**
     * Wheel radius in centimeters.
     */
    private double wheelRadius;
    private double axleTrack;

    private MovementStepMotorEntity leftMotor;
    private MovementStepMotorEntity rightMotor;
    private CameraStepMotorEntity cameraPanMotor;
    private CameraStepMotorEntity cameraTiltMotor;

    private final RulesManagerEntity rulesManagerEntity;

    public ArduinoRobot() {
        rulesManagerEntity = new RulesManagerEntity();
    }

    public void setHardwareData(double wheelRadius, double axleTrack, MovementStepMotorEntity leftMotor, MovementStepMotorEntity rightMotor, CameraStepMotorEntity cameraPanMotor, CameraStepMotorEntity cameraTiltMotor) {
        this.leftMotor = leftMotor;
        this.rightMotor = rightMotor;
        this.cameraPanMotor = cameraPanMotor;
        this.cameraTiltMotor = cameraTiltMotor;
        setWheelRadius(wheelRadius);
        setAxleTrack(axleTrack);
    }

    public RulesManagerEntity getRulesManagerEntity() {
        return rulesManagerEntity;
    }

    public void addRule(RuleEntity ruleEntity) {
        rulesManagerEntity.addRule(ruleEntity);
    }

    public double getWheelRadius() {
        return wheelRadius;
    }

    public void setWheelRadius(double wheelRadius) {
        this.wheelRadius = wheelRadius;
        rightMotor.setWheelRadius(wheelRadius);
        leftMotor.setWheelRadius(wheelRadius);
        rulesManagerEntity.setWheelRadius(wheelRadius);
    }

    public double getAxleTrack() {
        return axleTrack;
    }

    public void setAxleTrack(double axleTrack) {
        this.axleTrack = axleTrack;
    }

    public MovementStepMotorEntity getLeftMotor() {
        return leftMotor;
    }

    public MovementStepMotorEntity getRightMotor() {
        return rightMotor;
    }

    public CameraStepMotorEntity getCameraPanMotor() {
        return cameraPanMotor;
    }

    public CameraStepMotorEntity getCameraTiltMotor() {
        return cameraTiltMotor;
    }

    /**
     * Converts distance to number of steps (step motor), that it takes for a wheel with radius to travel the given distance.
     *
     * @param centimeters              Distance in centimeters
     * @param wheelRadiusInCentimeters Radius of the rotational wheel placed on the stepper motor
     * @param stepsPerRevolution       The number of steps that the motor makes for one revolution (360 degrees)
     * @return The number of steps that it takes to travel the given distance
     */
    public static int convertCentimetersToSteps(double centimeters, double wheelRadiusInCentimeters, final int stepsPerRevolution) {
        double pi = 3.141592;
        double wheelPerimeter = 2 * pi * wheelRadiusInCentimeters;

        double revolutionsToMake = centimeters / wheelPerimeter;

        return (int) (stepsPerRevolution * revolutionsToMake);
    }

    /**
     * Calculates the time in seconds that will take to rotate a step motor for a certain number of steps.
     *
     * @param steps Number of steps
     * @param speed Steps per second, rotational speed of the step motor.
     * @return The number of steps that it takes to travel the given distance
     */
    public static double convertStepsToSeconds(int steps, double speed) {
        return (double) steps / speed;
    }

    /**
     * Calculates the speed at which a motor must move to a certain number of steps in a for a given time.
     *
     * @param steps          Number of steps
     * @param timeToComplete The time for creating the given number of steps
     * @return Speed in steps per second
     */
    public static double convertStepsAndExecutionTimeToSpeed(int steps, double timeToComplete) {
        return (double) steps / timeToComplete;
    }

    /**
     * Converts degrees to number of steps (step motor), that it takes for a motor to move to the given number of degrees.
     *
     * @param degrees            degrees from current position
     * @param stepsPerRevolution The number of steps that the motor makes for one revolution (360 degrees)
     * @return The number of steps that it takes to move the given number of degrees
     */
    public static int convertDegreesToSteps(double degrees, final int stepsPerRevolution) {
        return (int) (stepsPerRevolution * degrees / 360);
    }
}

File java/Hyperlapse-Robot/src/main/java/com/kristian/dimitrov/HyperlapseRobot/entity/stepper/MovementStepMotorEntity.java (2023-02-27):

package com.kristian.dimitrov.HyperlapseRobot.entity.stepper;

import com.kristian.dimitrov.HyperlapseRobot.entity.ArduinoRobot;
import com.kristian.dimitrov.HyperlapseRobot.exception.IncompatibleStepMotorArguments;

import java.io.Serializable;
import java.text.DecimalFormat;

public class MovementStepMotorEntity extends StepMotorEntity implements Serializable {

    private static final DecimalFormat decimalFormat;

    static {
        decimalFormat = new DecimalFormat("#.####");
    }

    private double distance;
    private double executionTime;

    private final double wheelRadius;

    /**
     * <p>Default initialization of step motor entity with rule for distance and execution time.</p>
     */
    public MovementStepMotorEntity(double wheelRadius, int stepsPerRevolution, double maxSpeed) {
        super(stepsPerRevolution, maxSpeed);
        this.wheelRadius = wheelRadius;
    }

    /**
     * Clone constructor
     *
     * @param movementStepMotorEntity
     */
    public MovementStepMotorEntity(MovementStepMotorEntity movementStepMotorEntity) {
        this(movementStepMotorEntity.wheelRadius, movementStepMotorEntity.stepsPerRevolution, movementStepMotorEntity.maxSpeed);
    }

    /**
     * Sets the distance data and its travel completion time.
     *
     * @param distance      Distance to travel in centimeters
     * @param executionTime Time to complete in seconds
     * @throws IncompatibleStepMotorArguments When it is impossible to travel the given distance for the execution time, because of hardware limitations.
     */
    @Override
    public void setData(double distance, double executionTime) throws IncompatibleStepMotorArguments {
        double minimalTimeRequired = getMinimalTimeRequired(distance);

        if (minimalTimeRequired > executionTime)
            throw new IncompatibleStepMotorArguments("The given 'executionTime=" + executionTime + "' is too short for reaching the target 'distance=" + distance + "'. Minimal time for this distance is: " + minimalTimeRequired + " seconds");

        this.distance = distance;
        this.executionTime = executionTime;
    }

    @Override
    public double getMinimalTimeRequired(double distance) {
        int stepsRequired = ArduinoRobot.convertCentimetersToSteps(distance, wheelRadius, stepsPerRevolution);
        return ArduinoRobot.convertStepsToSeconds(stepsRequired, maxSpeed);
    }

    /**
     * @return distance in cm
     */
    @Override
    public double getMeasurementValue() {
        return distance;
    }

    /**
     * Does the same as getMeasurementValue().
     * The reason why this method exist is that the name of the method must follow the name convention of java spring.
     * Otherwise, there is a problem with receiving entity via http and parsing the values.
     *
     * @return distance in cm
     */
    public double getDistance() {
        return getMeasurementValue();
    }

    @Override
    public double getExecutionTime() {
        return executionTime;
    }

    @Override
    public String toString() {
        return "{" +
                "distance: " + decimalFormat.format(distance) +
                ", executionTime: " + executionTime +
                '}';
    }
}

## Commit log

2022-10-20 Uploading Java Spring project structure
2022-10-20 Service for controlling Continuous Rotation Servo
2022-10-20 Clockwise, Counter-Clockwise and STOP rest controllers for the servo motor added
2022-10-23 push current state of software
2022-10-30 missed code from last commit
    [arduino_hyperlapse_robot.ino]
2022-10-31 step motors array
2022-11-02 json implementation, bugs should be fixed for receiving data
    [arduino_hyperlapse_robot.ino]
2022-11-04 working state for handling multiple motors with json rules
2022-11-04 motors for camera renamed
2022-11-05 deletion of servo motor files
2022-11-05 I2C for sending string
2022-11-07 testing i2c
2022-11-08 sending large strings to arduino over i2c
2022-11-08 Temporary example of slave receiver for arduino
2022-11-10 interfacing arduino in java in progress
2022-11-14 send rules from RaspPi to Arduino
2022-11-15 stop arduino when java program gets turned off
2022-11-15 keyboard interrupt turning off
2022-11-15 motor in degrees control
2022-11-15 arduino tilt/pan control
2022-11-15 fix bugs when receiving multiple portions of rules from master
    [arduino_hyperlapse_robot.ino]
2022-11-30 not working http request
    [MainActivity.java]
2022-11-30 ArduinoServiceImpl::Use one thread instead of initializing every time
2022-11-30 trying to receive from arduino
2022-12-05 temporary hardware conf fix
    [HyperlapseRobotApplication.java]
2022-12-06 resolved http request error
    [MainActivity.java]
2022-12-08 rounded views + camera rules designed
2022-12-13 configure conn error fixeed
    [ArduinoRobot.java, MainActivity.java]
2022-12-19 trying to repair bugs
    [MainActivity.java, RuleEntity.java, RulesManagerEntity.java]
2022-12-19 staged rules display
2022-12-20 completed flow
2022-12-22 camera inputs redesign
2022-12-23 replace errors dialog with warning dialog
    [CreateRuleActivity.java]
2022-12-29 staged rules layout update
2023-01-03 uploading with compile errors
    [CreateRuleActivity.java, ForwardBackwardFragment.java, MainActivity.java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]
2023-01-03 edit staged rules
2023-01-03 simpler staged rule description
2023-01-06 buzzer sound before every rule
    [arduino_hyperlapse_robot.ino]
2023-01-09 major bug fixed for rotating at very low speed
    [arduino_hyperlapse_robot.ino]
2023-01-09 better input buttons autofillers
2023-01-11 standartized wheel radius for frontend and backend
2023-01-11 backend wheelRadius added to stagedRules.toString()
2023-01-11 frontend/backend wheel radius
2023-01-11 arduino receive wheel radius in rules
2023-01-20 conventional method names in backend resolved problem
    [CameraStepMotorEntity.java, MainActivity.java, MovementStepMotorEntity.java]
2023-01-25 replace unecessary double return
    [arduino_hyperlapse_robot.ino]
2023-01-30 upload 3D print stl
    [bigGear.stl, gearHolder.stl, heavierWheel.stl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]
2023-01-30 assemblied blender file
    [assembly.blend]
2023-02-02 resolved empty chunks for i2c
    [ArduinoServiceImpl.java, arduino_hyperlapse_robot.ino]
2023-02-02 control box body,mid,top
    [controlBoxBody.stl, controlBoxTop.stl]
2023-02-05 3d-print update
    [assembly-box90degHolder.stl, assembly-boxControllerTop.stl, assembly-circuitPlate.stl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]
2023-02-08 upload upper components
    [assembly-boxControllerTop.stl, assembly-circuitPlate.stl, assembly-controlBoxBody1.stl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]
2023-02-08 removed part of the bugs
    [ArduinoRobot.java, MainActivity.java, MovementStepMotorEntity.java]
2023-02-08 resolved long distance problem
    [arduino_hyperlapse_robot.ino]
2023-02-13 change motor pins
2023-02-14 display turn data in staget rules adapter + editing
